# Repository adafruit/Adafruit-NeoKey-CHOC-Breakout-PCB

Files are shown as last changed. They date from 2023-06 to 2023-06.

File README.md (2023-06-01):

## Adafruit NeoKey CHOC Breakout PCB

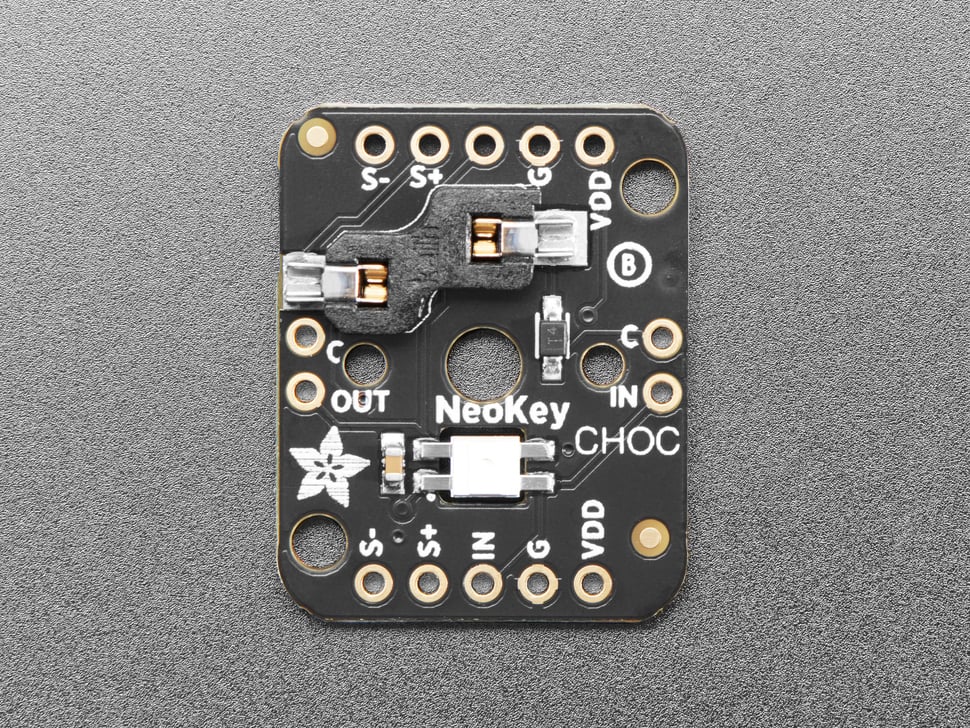
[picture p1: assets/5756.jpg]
<a href="http://www.adafruit.com/products/5756"><br/>
Click here to purchase one from the Adafruit shop</a>

PCB files for the Adafruit NeoKey CHOC Breakout. 

Format is EagleCAD schematic and board layout
* https://www.adafruit.com/product/5756

### Description

The only thing better than a nice mechanical key, is one that also can glow any color of the rainbow - and that's what the Adafruit NeoKey Breakout will let you do! This little 0.75" x 0.95" PCB can fit one Kailh CHOC or compatible switch and make it easy to use with a breadboard or perfboard.

The breakout has a Kailh CHOC socket, which means you can plug in any CHOC-compatible switch instead of soldering it in. You may need a little glue to keep the switch in place; hot glue or a dot of epoxy worked fine for us. We also place a 1N4148 signal diode in series with the switch, so you can create key-grid matrices without worrying about ghosted keys.

Each breakout also has a single reverse-mount NeoPixel pointing up through the spot where many switches would have an LED to shine through. The input and output of the pixel are broken out so you can 'chain' these boards together and control them as one NeoPixel strand.

There's plenty of flexibility for any kind of use; each board has the following pin out:

* VDD (+) The power pin for the NeoPixel; provide 3 to 5VDC
* GND (-) The ground power pin for the NeoPixel, connect to ground
* In (I) and Out (O) The input and output to/from the NeoPixel, for chaining
* Switch Anode (A) - The 'positive' side of the switch+diode. If you're using the switch with a pull-up resistor, connect this pin to your microcontroller. If you're using a pull-down, connect this pin to your logic level power pin.
* Switch Cathode (C) - The 'negative' side of the switch+diode. If you're using the switch with a pull-up resistor, connect this pin to ground. If you're using a pull-down, connect this pin to your microcontroller.

There're two rows of 5-pin contacts on a 0.1" grid on both sides. Solder in both sides for mechanical stability; the two sides share the same pins except for one side is NeoPixel in and the opposite side has the out pin. For side-by-side wiring, we also have the cathode pin broken out on the sides, and another set of NeoPixel In/Out pins.

Please note, each order comes with one assembled PCB and a small stick of break-off header. Soldering is required to attach the header for breadboard use. A mechanical switch and key cap are not included! Use any CHOC-compatible switch. Note that Cherry/MX switches are not at all compatible with CHOC sockets.

### License

Adafruit invests time and resources providing this open source design, please support Adafruit and open-source hardware by purchasing products from [Adafruit](https://www.adafruit.com)!

Designed by Limor Fried/Ladyada for Adafruit Industries.

Creative Commons Attribution/Share-Alike, all text above must be included in any redistribution. 
See license.txt for additional details.

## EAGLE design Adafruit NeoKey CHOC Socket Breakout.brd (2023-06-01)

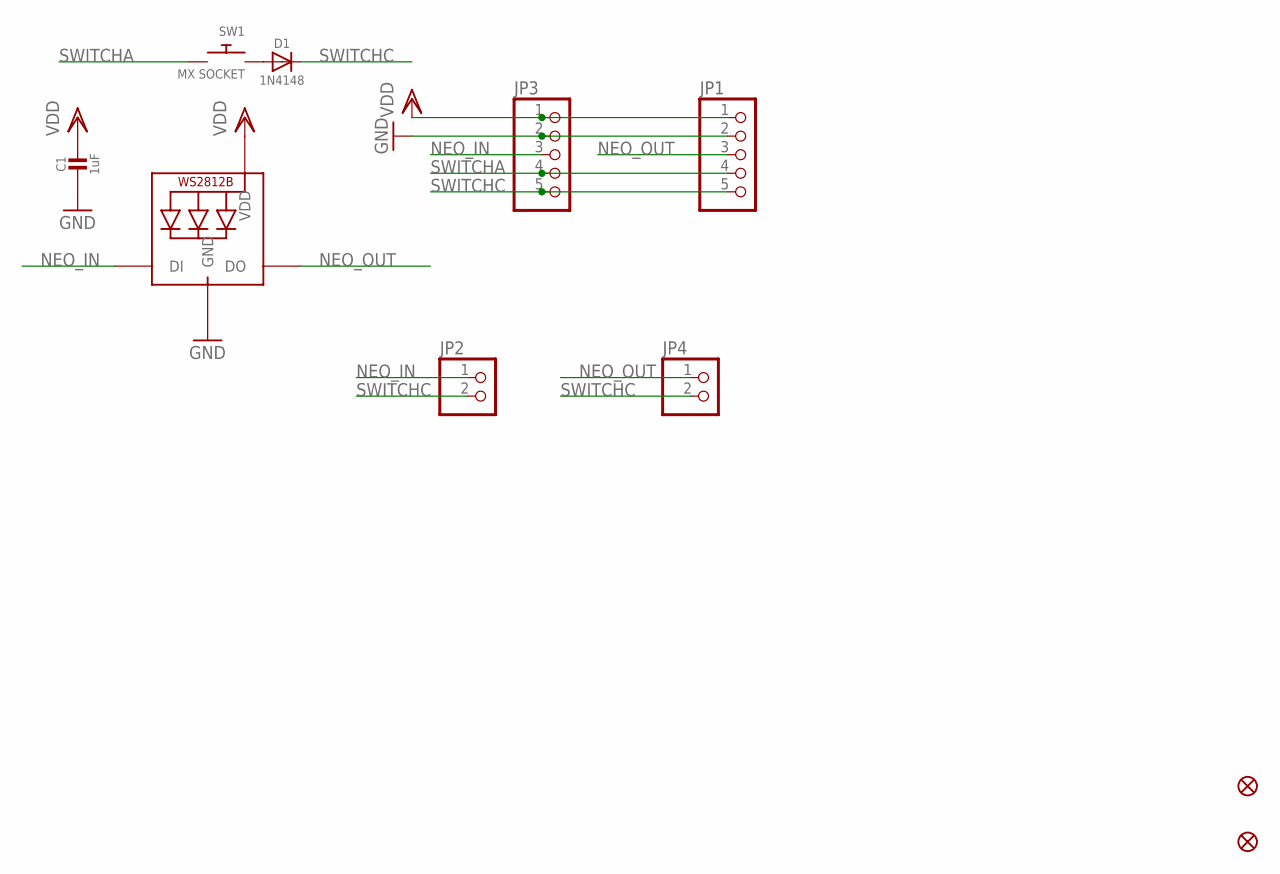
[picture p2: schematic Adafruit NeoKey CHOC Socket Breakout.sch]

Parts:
C1: 1uF; 0603-NO
D1: 1N4148; SOD-323
FID3, FID4: FIDUCIAL_1MM
JP1, JP3: HEADER-1X570MIL; 1X05_ROUND_70
JP2, JP4: HEADER-1X2ROUND; 1X02_ROUND
LED1: WS2812B_SK6812E; NEO3535_REVERSE
SW1: MX SOCKET; KAILH_CHOC_SOCKET

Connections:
GND: C1.2, JP1.2, JP3.2, LED1.3-GND (GND)
unnamed: D1.A, SW1.1
NEO_IN: JP2.1, JP3.3, LED1.4-DIN (DI)
NEO_OUT: JP1.3, JP4.1, LED1.2-DOUT (DO)
SWITCHA: JP1.4, JP3.4, SW1.2
SWITCHC: D1.C, JP1.5, JP2.2, JP3.5, JP4.2
VDD: C1.1, JP1.1, JP3.1, LED1.1-VDD (VDD)

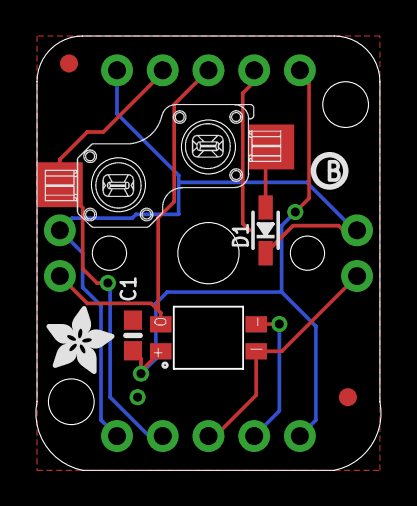
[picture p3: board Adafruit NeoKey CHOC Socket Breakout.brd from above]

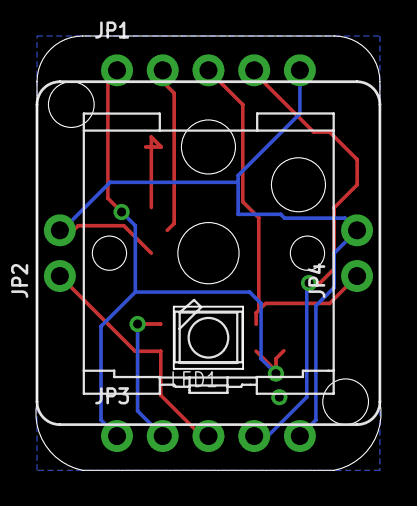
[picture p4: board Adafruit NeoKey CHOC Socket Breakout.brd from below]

Board: 2 copper layers, 19.2 x 24.1 mm, 37 parts (16 on the bottom side), 7 nets.

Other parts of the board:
PLABEL0, PLABEL20: PLABEL0
PLABEL1: PLABEL1
PLABEL2: PLABEL2
PLABEL3: PLABEL3
PLABEL4: PLABEL4
PLABEL5: PLABEL5
PLABEL6, PLABEL21: PLABEL6
PLABEL7: PLABEL7
PLABEL8, PLABEL22: PLABEL8
PLABEL9, PLABEL23: PLABEL9
PLABEL10: PLABEL10
PLABEL11: PLABEL11
PLABEL12: PLABEL12
PLABEL13: PLABEL13
PLABEL14: PLABEL14
PLABEL15: PLABEL15
PLABEL16: PLABEL16
PLABEL17: PLABEL17
PLABEL18: PLABEL18
PLABEL19: PLABEL19
PLABEL200: PLABEL200
U$1: PCBFEAT-REV-040
U$2: ADAFRUIT_3.5MM

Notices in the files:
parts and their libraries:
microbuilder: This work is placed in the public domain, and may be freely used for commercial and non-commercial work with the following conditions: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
